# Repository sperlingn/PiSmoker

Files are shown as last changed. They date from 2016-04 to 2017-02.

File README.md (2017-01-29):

# PiSmoker

##Dependencies
* RPI.GPIO
* spidev
* [Adafruit_Python_CharLCD](https://github.com/adafruit/Adafruit_Python_CharLCD)
* [Python-firebase](https://github.com/ozgur/python-firebase) Use github version instead of pip

## Schematics and Boards
* PiSmoker_pwr_triac_isol -- AC handling board, includes SW PS for backpowering Raspi.
* PiSmoker_sig_v1.1 -- Signal boards, conforms to Pi HAT specifications, including EEPROM.

Signal board and power board for traic based control.  Includes board power with isolation and 4 triacs.  Signaling board has space for 1 RTD via MAX31865, 2 thermocouples (and internal temperature sensor) via ADS1118, and 2 thermocouples and 4 thermistor probes via MCP3208.  Using MAX31865 temperature for CJC for all thermocouples should be possible due to placement underneath connector.

## Work to be done

* TODO: Add support for firebox burnout sensor (purpose of TC1, hotbox TC to see if temp is >setpoint, will require testing temps).  Should be able to run igniter if it is sensed early enough without having to clear out the firebox of pellets or blow the temperature range.
* TODO: Add parsing of EEPROM settings.

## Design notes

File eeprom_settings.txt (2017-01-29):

########################################################################
# EEPROM settings text file
#
# Edit this file for your particular board and run through eepmake tool,
# then use eepflash tool to write to attached HAT ID EEPROM
#
# Tools available:
#  eepmake   Parses EEPROM text file and creates binary .eep file
#  eepdump   Dumps a binary .eep file as human readable text (for debug)
#  eepflash  Write or read .eep binary image to/from HAT EEPROM
#
########################################################################

########################################################################
# Vendor info

# 128 bit UUID. If left at zero eepmake tool will auto-generate
# RFC 4122 compliant UUID
product_uuid 00000000-0000-0000-0000-000000000000

# 16 bit product id
product_id 0x0001

# 16 bit product version
product_ver 0x0001

# ASCII vendor string  (max 255 characters)
vendor "PiSmoker"

# ASCII product string (max 255 characters)
product "PiSmoker interface board v1.1"

########################################################################
# GPIO bank settings, set to nonzero to change from the default.
# NOTE these setting can only be set per BANK, uncommenting any of
# these will force the bank to use the custom setting.

# drive strength, 0=default, 1-8=2,4,6,8,10,12,14,16mA, 9-15=reserved
gpio_drive 4

# 0=default, 1=slew rate limiting, 2=no slew limiting, 3=reserved
gpio_slew 0

# 0=default, 1=hysteresis disabled, 2=hysteresis enabled, 3=reserved
gpio_hysteresis 0

# If board back-powers Pi via 5V GPIO header pins:
# 0 = board does not back-power
# 1 = board back-powers and can supply the Pi with a minimum of 1.3A
# 2 = board back-powers and can supply the Pi with a minimum of 2A
# 3 = reserved
# If back_power=2 then USB high current mode will be automatically
# enabled on the Pi
back_power 2

########################################################################
# GPIO pins, uncomment for GPIOs used on board
# Options for FUNCTION: INPUT, OUTPUT, ALT0-ALT5
# Options for PULL: DEFAULT, UP, DOWN, NONE
# NB GPIO0 and GPIO1 are reserved for ID EEPROM so cannot be set

#         GPIO  FUNCTION  PULL
#         ----  --------  ----
setgpio  2     OUTPUT     NONE
setgpio  3     OUTPUT     NONE
setgpio  4     OUTPUT     NONE
setgpio  5     OUTPUT     NONE
#setgpio  6     INPUT     DEFAULT
#setgpio  7     INPUT     DEFAULT
#setgpio  8     INPUT     DEFAULT
#setgpio  9     INPUT     DEFAULT
#setgpio  10    INPUT     DEFAULT
#setgpio  11    INPUT     DEFAULT
#setgpio  12    INPUT     DEFAULT
#setgpio  13    INPUT     DEFAULT
#setgpio  14    INPUT     DEFAULT
#setgpio  15    INPUT     DEFAULT
setgpio  16    ALT4     DEFAULT
setgpio  17    ALT4     DEFAULT
setgpio  18    ALT4     DEFAULT
setgpio  19    ALT4     DEFAULT
setgpio  20    ALT4     DEFAULT
setgpio  21    ALT4     DEFAULT
#setgpio  22    INPUT     DEFAULT
#setgpio  23    INPUT     DEFAULT
#setgpio  24    INPUT     DEFAULT
#setgpio  25    INPUT     DEFAULT
#setgpio  26    INPUT     DEFAULT
#setgpio  27    INPUT     DEFAULT

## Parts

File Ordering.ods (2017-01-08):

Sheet: MOUSER
 |  |  | PISMOKER
Order Qty. | P# | Qty | Mouser # | Mfr. # | Manufacturer | Customer # | Description | RoHS | Lifecycle | Order Qty. | Price (USD) | Ext.: (USD)
1 | 21 | 1 | 579-MCP3208CISL | MCP3208-CI/SL | Microchip |  | Analog to Digital Converters - ADC 12-bit SPI 8 Chl | RoHS Compliant |  | 1 | $3.66 | $3.66
1 | 18 | 1 | 595-ADS1118IDGSR | ADS1118IDGSR | Texas Instruments |  | Analog to Digital Converters - ADC 16B ADC w/Integrated MUX | RoHS Compliant |  | 1 | $5.48 | $5.48
1 | 20 | 1 | 700-MAX31865AAP+ | MAX31865AAP+ | Maxim Integrated |  | Data Acquisition ADCs/DACs - Specialized | RoHS Compliant | New At Mouser | 1 | $3.47 | $3.47
2 | 20 | 1 | 660-RN732BTTD4001B25 | RN732BTTD4001B25 | KOA Speer |  | Thin Film Resistors - SMD 4kOhm,1206,0.1%,25pp m,125mW,150V | RoHS Compliant By Exemption |  | 2 | $0.49 | $0.98
4 | 20 | 1 | 588-AS08J1001ET | AS08J1001ET | Ohmite |  | Thick Film Resistors - SMD 330 mW 1000 OHM 5% ANTI SURGE | RoHS Compliant | New At Mouser | 4 | $0.06 | $0.24
8 | 20 | #N/A | 538-03-06-2023 | 03-06-2023 | Molex |  | Pin & Socket Connectors 2 CKT PLUG NATURAL | RoHS Compliant |  | 8 | $0.18 | $1.44
16 | 20 | #N/A | 538-02-06-2103 | 02-06-2103 | Molex |  | Pin & Socket Connectors CRIMP PIN BULK 18-24 | RoHS Compliant |  | 16 | $0.117 | $1.87
3 | 20 | 1 | 698-CAT24C256WI-GT3 | CAT24C256WI-GT3 | ON Semiconductor |  | EEPROM 256kb I2C Serial CMOS EEPROM | RoHS Compliant |  | 3 | $0.65 | $1.95
1 | 20 | 1 | 709-IRM20-5 | IRM-20-5 | Mean Well |  | AC/DC Power Modules 5V 4A 20W 85-264Vin Encap PS | RoHS Compliant |  | 1 | $11.07 | $11.07
1 | 20 | #N/A | 611-DA102J3RS215QF8 | DA102J3RS215QF8 | C&K Components |  | Illuminated Rocker Switches SPST 16A ON-OFF RED | RoHS Compliant |  | 1 | $1.16 | $1.16
10 | 20 | 13 | 710-885012207072 | 885012207072 | Wurth Electronics |  | Multilayer Ceramic Capacitors MLCC - SMD/SMT WCAP-CSGP 100000pF 0805 10% 25V MLCC | RoHS Compliant | New Product | 10 | $0.05 | $0.50
10 | 20 | 1 | 710-885012207011 | 885012207011 | Wurth Electronics |  | Multilayer Ceramic Capacitors MLCC - SMD/SMT WCAP-CSGP 10000pF 0805 10% 10V MLCC | RoHS Compliant | New Product | 10 | $0.07 | $0.70
5 | 20 | 2 | 755-ESR10EZPJ392 | ESR10EZPJ392 | ROHM Semiconductor |  | Thick Film Resistors - SMD 0805 3K9ohm 5% Anti Surge AEC-Q200 | RoHS Compliant | New Product | 5 | $0.10 | $0.50
3 | 20 | 1 | 621-DMG2305UX-7 | DMG2305UX-7 | Diodes Incorporated |  | MOSFET P-Ch ENH FET -20V 52mOhm -5.0V | RoHS Compliant |  | 3 | $0.37 | $1.11
3 | 20 | 1 | 621-DMMT5401-7-F | DMMT5401-7-F | Diodes Incorporated |  | Bipolar Transistors - BJT MATCHED PNP SM SIGNAL TRANS | RoHS Compliant |  | 3 | $0.42 | $1.26
3 | 20 | 1 | 71-CRCW0805-47K-E3 | CRCW080547K0FKEA | Vishay |  | Thick Film Resistors - SMD 1/8watt 47Kohms 1% 100ppm | RoHS Compliant By Exemption |  | 3 | $0.10 | $0.30
14 | 20 | 8 | 588-AS08J1004ET | AS08J1004ET | Ohmite |  | Thick Film Resistors - SMD 330 mW 1mOhm 5% ANTI SURGE | RoHS Compliant | New At Mouser | 14 | $0.048 | $0.67
14 | 20 | 8 | 652-CR0805FX-4990ELF | CR0805-FX-4990ELF | Bourns |  | Thick Film Resistors - SMD 499ohm 1% | RoHS Compliant By Exemption |  | 14 | $0.038 | $0.53
10 | 20 | 4 | 77-VJ0805Y105KXQTBC | VJ0805Y105KXQTW1BC | Vishay |  | Multilayer Ceramic Capacitors MLCC - SMD/SMT 0805 1uF 10volts X7R 10% | RoHS Compliant |  | 10 | $0.05 | $0.50
8 | 20 | #N/A | 855-R25-1001302 | R25-1001302 | Harwin |  | Standoffs & Spacers M2.5 x 13mm HEX BRASS 5mm A/F | RoHS Compliant By Exemption |  | 8 | $0.44 | $3.52
10 | 20 | 4 | 279-CPF0805B22KE1 | CPF0805B22KE | TE Connectivity |  | Thin Film Resistors - SMD CPF0805 22K 0.1% 25PPM | RoHS Compliant |  | 10 | $0.15 | $1.50
10 | 20 | 1 | 284-APC0805B10K0N | APC0805B10K0N | Ohmite |  | Thin Film Resistors - SMD 10KOhm 0.1% 0805 25 PPM | RoHS Compliant | New Product | 10 | $0.097 | $0.97
2 | 20 | 2 | 855-M20-7812045 | M20-7812045 | Harwin |  | Headers & Wire Housings 20+20 DIL 2.54MM L/P SMT SKT | RoHS Compliant | New Product | 2 | $3.96 | $7.92
2 | 20 | 2 | 855-M20-8762042 | M20-8762042 | Harwin |  | Headers & Wire Housings 20+20 DIL VERTICAL SMT HEADER GOLD+TIN | RoHS Compliant |  | 2 | $2.05 | $4.10
2 | 20 | 2 | 855-M20-7872042 | M20-7872042 | Harwin |  | Headers & Wire Housings 20+20 DIL SMT SKT BTM ENT SEL GLD+TIN | RoHS Compliant |  | 2 | $4.97 | $9.94
25 | 20 | 16 | 667-ERJ-P06J301V | ERJ-P06J301V | Panasonic |  | Thick Film Resistors - SMD 0805 300ohms 5% Thick Film Resistor | RoHS Compliant By Exemption |  | 25 | $0.058 | $1.45
5 | 20 | 4 | 771-BTA312B-800E,118 | BTA312B-800E,118 | NXP |  | Triacs Thyristor TRIAC 800V 105A 3-Pin (2+Tab) | RoHS Compliant |  | 5 | $1.07 | $5.35
5 | 20 | 4 | 638-EL3063S1TAV | EL3063S1(TA)-V | Everlight |  | Triac & SCR Output Optocouplers 600PBV 5000Vrms -55 to +100 Op Temp | RoHS Compliant |  | 5 | $0.97 | $4.85
6 | 20 | 4 | 810-CGA5L4C0G2J103J | CGA5L4C0G2J103J160AA | TDK |  | Multilayer Ceramic Capacitors MLCC - SMD/SMT 1206 0.01uF 630volts C0G +/-5% Auto | RoHS Compliant |  | 6 | $0.49 | $2.94
1 | 20 | 1 | 693-0031.8263 | 0031.8263 | Schurter |  | Fuse Holder OGN-SMD FUSEHOLDER 5X20 | RoHS Compliant |  | 1 | $1.39 | $1.39
1 | 20 | 1 | 651-1771088 | 1771088 | Phoenix Contact |  | Fixed Terminal Blocks PTSM 0,5/ 8-2,5-H SMD R44 | RoHS Compliant |  | 1 | $1.40 | $1.40
1 | 20 | 1 | 651-1771062 | 1771062 | Phoenix Contact |  | Fixed Terminal Blocks PTSM 0,5/ 6-2,5-H SMD R44 | RoHS Compliant |  | 1 | $1.22 | $1.22

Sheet: QTY
Qty | Value | Device | Package | Mouser | Parts | Description | TOLERANCE
1 |  | PHOENIX_PTS1,5-6PTSM0,5 | PHOENIX_PTSM0,5/6-2,5-H_SMD_R44 | 651-1771062 | X2 | PHOENIX
1 |  | TERMINAL_BLOCK-8PTSM0,5 | PHOENIX_PTSM0,5/8-2,5-H_SMD_R44 | 651-1771088 | X1 | PHOENIX
13 | 100nF | C-EUC0805K | C0805K | 710-885012207072 | C1, C3, C4, C5, C6, C7, C9, C10, C12, C13, C15, C16, C17 | CAPACITOR, European symbol
1 | 10nF | C-EUC0805 | C0805 | 710-885012207011 | C2 | CAPACITOR, European symbol
4 | 10nF | C-EUC1206 | C1206 | 810-CGA5L4C0G2J103J | C1, C2, C3, C4 | CAPACITOR, European symbol
4 | 1uF | C-EUC0805K | C0805K | 77-VJ0805Y105KXQTBC | C8, C11, C14, C18 | CAPACITOR, European symbol
8 | 1M | R-EU_M0805 | M0805 | 588-AS08J1004ET | R8, R9, R12, R13, R16, R17, R20, R21 | RESISTOR, European symbol | 5%
1 | 47k | R-EU_M0805 | M0805 | 71-CRCW0805-47K-E3 | R2 | RESISTOR, European symbol | 1%
4 | 22k | R-EU_R0805 | R0805 | 279-CPF0805B22KE1 | R6, R24, R26, R28 | RESISTOR, European symbol | 0.10%
1 | 10K | R-EU_M0805 | M0805 | 284-APC0805B10K0N | R1 | RESISTOR, European symbol | 1%
4 | 10k | R-EU_R0805 | R0805 | 284-APC0805B10K0N | R5, R23, R25, R27 | RESISTOR, European symbol | 0.10%
1 | 4k | R-EU_R1206 | R1206 | 660-RN732BTTD4001B25 | R4 | RESISTOR, European symbol | 0.10%
2 | 3k9 | R-EU_M0805 | M0805 | 755-ESR10EZPJ392 | R1, R2 | RESISTOR, European symbol | 5%
1 | 1k | R-EU_M0805 | M0805 | 588-AS08J1001ET | R3 | RESISTOR, European symbol | 5%
8 | 499 | R-EU_M0805 | M0805 | 652-CR0805FX-4990ELF | R7, R10, R11, R14, R15, R18, R19, R22 | RESISTOR, European symbol | 5%
16 | 300 | R-EU_M0805 | M0805 | 667-ERJ-P06J301V | R3, R4, R5, R6, R7, R8, R9, R10, R11, R12, R13, R14, R15, R16, R17, R18 | RESISTOR, European symbol | 5%
1 | ADS1118 | ADS1118 | DGS10 | 595-ADS1118IDGSR | U$1 | ADS1118
1 | EEPROM24 | CAT24C256WI-GT3 | SOIC8 | 698-CAT24C256WI-GT3 | U1
1 | MAX31865 | MAX31865 | SSOP20_A20-1 | 700-MAX31865AAP+ | U$2 | RTD to Digital Converter
1 | MCP3208 | MCP3208 | SOIC16-N_MC | 579-MCP3208CISL | U$3
1 | 5AL250V | OGN_FUSE | OGN_SMD | 693-0031.8263 | F1 | FUSE HOLDER grid 22,5 mm, OGN0031 8201, Schurter (Buerklin)
1 | 5V | IRM_15/20 | IRM_15/20 | 709-IRM20-5 | IRM-20-5 | 15 or 20 watt
1 | BSS84 | BSS84 | SOT23 | 621-DMG2305UX-7 | Q1 | P-CHANNEL MOS FET
4 | BTA312B | BTA312B | D2PAK-3 | 771-BTA312B-800E,118 | U1, U2, U3, U4
4 | EL3063S1 | EL3063S1 | SMD6 | 638-EL3063S1TAV | OK1, OK2, OK3, OK4 | 6-Pin DIP Zero-Cross Optoisolators Triac Driver Output (250/400 Volt Peak)
1 | PNP2 | PNP2 | SOT26 | 621-DMMT5401-7-F | T1 | Dual PNP TRANSISTOR
2 |  | M20-781_SMD | M20-781_SMD_LOWER_NOHOLES | 855-M20-7812045 | X1 | 2x20 header connector, all pins connected
2 |  | M20-876_SMD | M20-781_SMD_LOWER_876_UPPER | 855-M20-8762042 | X3 | 2x20 header connector, all pins connected
2 |  |  |  | 855-M20-7872042

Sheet: Signal_Board_Placement
Part | Value | Device | Package | Description | COPYRIGHT | DATASHEETURL | DIELECTRIC | FAMILY_NAME | GENERIC_PART_NUMBER | INDUSTRY_STD_PKG_TYPE | MANUFACTURER | MANUFACTURER_PART_NUMBER | P1 | P2 | P3 | P4 | P5 | P6 | P7 | P8 | PACKAGE_DESIGNATOR | PIN_COUNT | TOLERANCE | VENDOR
C1 | 100nF | C-EUC0805K | C0805K | CAPACITOR, European symbol |  |  | X7R
C2 | 10nF | C-EUC0805 | C0805 | CAPACITOR, European symbol
C3 | 100nF | C-EUC0805K | C0805K | CAPACITOR, European symbol |  |  | X7R
C4 | 100nF | C-EUC0805K | C0805K | CAPACITOR, European symbol |  |  | X7R
C5 | 100nF | C-EUC0805K | C0805K | CAPACITOR, European symbol |  |  | X7R
C6 | 100nF | C-EUC0805K | C0805K | CAPACITOR, European symbol |  |  | X7R
C7 | 100nF | C-EUC0805K | C0805K | CAPACITOR, European symbol |  |  | X7R
C8 | 1uF | C-EUC0805K | C0805K | CAPACITOR, European symbol |  |  | X7R
C9 | 100nF | C-EUC0805K | C0805K | CAPACITOR, European symbol |  |  | X7R
C10 | 100nF | C-EUC0805K | C0805K | CAPACITOR, European symbol |  |  | X7R
C11 | 1uF | C-EUC0805K | C0805K | CAPACITOR, European symbol |  |  | X7R
C12 | 100nF | C-EUC0805K | C0805K | CAPACITOR, European symbol |  |  | X7R
C13 | 100nF | C-EUC0805K | C0805K | CAPACITOR, European symbol |  |  | X7R
C14 | 1uF | C-EUC0805K | C0805K | CAPACITOR, European symbol |  |  | X7R
C15 | 100nF | C-EUC0805K | C0805K | CAPACITOR, European symbol |  |  | X7R
C16 | 100nF | C-EUC0805K | C0805K | CAPACITOR, European symbol |  |  | X7R
C17 | 100nF | C-EUC0805K | C0805K | CAPACITOR, European symbol |  |  | X7R
C18 | 1uF | C-EUC0805K | C0805K | CAPACITOR, European symbol |  |  | X7R
CFG |  | SOLDERJUMPERCLOSED | SOLDERJUMPER_CLOSEDWIRE | SMD Solder JUMPER
R1 | 3k9 | R-EU_M0805 | M0805 | RESISTOR, European symbol |  |  |  |  |  |  |  |  |  |  |  |  |  |  |  |  |  |  | 5%
R2 | 3k9 | R-EU_M0805 | M0805 | RESISTOR, European symbol |  |  |  |  |  |  |  |  |  |  |  |  |  |  |  |  |  |  | 5%
R3 | 1k | R-EU_M0805 | M0805 | RESISTOR, European symbol |  |  |  |  |  |  |  |  |  |  |  |  |  |  |  |  |  |  | 5%
R4 | 4k | R-EU_R1206 | R1206 | RESISTOR, European symbol |  |  |  |  |  |  |  |  |  |  |  |  |  |  |  |  |  |  | 0.10%
R5 | 10k | R-EU_R0805 | R0805 | RESISTOR, European symbol |  |  |  |  |  |  |  |  |  |  |  |  |  |  |  |  |  |  | 0.10%
R6 | 22k | R-EU_R0805 | R0805 | RESISTOR, European symbol |  |  |  |  |  |  |  |  |  |  |  |  |  |  |  |  |  |  | 0.10%
R7 | 499 | R-EU_M0805 | M0805 | RESISTOR, European symbol |  |  |  |  |  |  |  |  |  |  |  |  |  |  |  |  |  |  | 5%
R8 | 1M | R-EU_M0805 | M0805 | RESISTOR, European symbol |  |  |  |  |  |  |  |  |  |  |  |  |  |  |  |  |  |  | 5%
R9 | 1M | R-EU_M0805 | M0805 | RESISTOR, European symbol |  |  |  |  |  |  |  |  |  |  |  |  |  |  |  |  |  |  | 5%
R10 | 499 | R-EU_M0805 | M0805 | RESISTOR, European symbol |  |  |  |  |  |  |  |  |  |  |  |  |  |  |  |  |  |  | 5%
R11 | 499 | R-EU_M0805 | M0805 | RESISTOR, European symbol |  |  |  |  |  |  |  |  |  |  |  |  |  |  |  |  |  |  | 5%
R12 | 1M | R-EU_M0805 | M0805 | RESISTOR, European symbol |  |  |  |  |  |  |  |  |  |  |  |  |  |  |  |  |  |  | 5%
R13 | 1M | R-EU_M0805 | M0805 | RESISTOR, European symbol |  |  |  |  |  |  |  |  |  |  |  |  |  |  |  |  |  |  | 5%
R14 | 499 | R-EU_M0805 | M0805 | RESISTOR, European symbol |  |  |  |  |  |  |  |  |  |  |  |  |  |  |  |  |  |  | 5%
R15 | 499 | R-EU_M0805 | M0805 | RESISTOR, European symbol |  |  |  |  |  |  |  |  |  |  |  |  |  |  |  |  |  |  | 5%
R16 | 1M | R-EU_M0805 | M0805 | RESISTOR, European symbol |  |  |  |  |  |  |  |  |  |  |  |  |  |  |  |  |  |  | 5%
R17 | 1M | R-EU_M0805 | M0805 | RESISTOR, European symbol |  |  |  |  |  |  |  |  |  |  |  |  |  |  |  |  |  |  | 5%
R18 | 499 | R-EU_M0805 | M0805 | RESISTOR, European symbol |  |  |  |  |  |  |  |  |  |  |  |  |  |  |  |  |  |  | 5%
R19 | 499 | R-EU_M0805 | M0805 | RESISTOR, European symbol |  |  |  |  |  |  |  |  |  |  |  |  |  |  |  |  |  |  | 5%
R20 | 1M | R-EU_M0805 | M0805 | RESISTOR, European symbol |  |  |  |  |  |  |  |  |  |  |  |  |  |  |  |  |  |  | 5%
R21 | 1M | R-EU_M0805 | M0805 | RESISTOR, European symbol |  |  |  |  |  |  |  |  |  |  |  |  |  |  |  |  |  |  | 5%
R22 | 499 | R-EU_M0805 | M0805 | RESISTOR, European symbol |  |  |  |  |  |  |  |  |  |  |  |  |  |  |  |  |  |  | 5%
R23 | 10k | R-EU_R0805 | R0805 | RESISTOR, European symbol |  |  |  |  |  |  |  |  |  |  |  |  |  |  |  |  |  |  | 0.10%
R24 | 22k | R-EU_R0805 | R0805 | RESISTOR, European symbol |  |  |  |  |  |  |  |  |  |  |  |  |  |  |  |  |  |  | 0.10%
R25 | 10k | R-EU_R0805 | R0805 | RESISTOR, European symbol |  |  |  |  |  |  |  |  |  |  |  |  |  |  |  |  |  |  | 0.10%
R26 | 22k | R-EU_R0805 | R0805 | RESISTOR, European symbol |  |  |  |  |  |  |  |  |  |  |  |  |  |  |  |  |  |  | 0.10%
R27 | 10k | R-EU_R0805 | R0805 | RESISTOR, European symbol |  |  |  |  |  |  |  |  |  |  |  |  |  |  |  |  |  |  | 0.10%
R28 | 22k | R-EU_R0805 | R0805 | RESISTOR, European symbol |  |  |  |  |  |  |  |  |  |  |  |  |  |  |  |  |  |  | 0.10%
SJ1 |  | SOLDERJUMPER_2WAY | SOLDERJUMPER_2WAY_ARROW_NOPASTE | 2-Way Solder Jumper
SJ2 |  | SOLDERJUMPER_2WAY | SOLDERJUMPER_2WAY_ARROW_NOPASTE | 2-Way Solder Jumper
SJ3 |  | SOLDERJUMPER_2WAY | SOLDERJUMPER_2WAY_ARROW_NOPASTE | 2-Way Solder Jumper
SJ4 |  | SOLDERJUMPER_2WAY | SOLDERJUMPER_2WAY_ARROW_NOPASTE | 2-Way Solder Jumper
U$1 | ADS1118 | ADS1118 | DGS10 | ADS1118 | Copyright C 2015 Accelerated Designs. All rights reserved | httpwww.ti.comlitgpnADS1118 |  | PRECISION ADC <=10MSPS | ADS1118 | MSOP | Texas Instruments | ADS1118_DGS_10 |  |  |  |  |  |  |  |  | DGS | 10 |  | Texas Instruments
U$2 | MAX31865 | MAX31865 | SSOP20_A20-1 | RTD to Digital Converter
U$3 | MCP3208 | MCP3208 | SOIC16-N_MC
U1 | EEPROM24 | EEPROM24 | SOIC8
X1 |  | TERMINAL_BLOCK-8PTSM0,5 | PHOENIX_PTSM0,5/8-2,5-H_SMD_R44 | PHOENIX |  |  |  |  |  |  |  |  | RTD1+ | RTD1- | TC1+ | TC1- | TC2- | TC2+ | TC3+ | TC3-
X2 |  | PHOENIX_PTS1,5-6PTSM0,5 | PHOENIX_PTSM0,5/6-2,5-H_SMD_R44 | PHOENIX |  |  |  |  |  |  |  |  | TC4+ | TC4- | RT1+ | RT2+ | RT3+ | RT4+
X3 | RASPI_GPIO_3B_SPI1_M20-781LOWER-876_UPPER | RASPI_GPIO_3B_SPI1_M20-781LOWER-876_UPPER | M20-781_SMD_LOWER_876_UPPER | 2x20 header connector, all pins connected

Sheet: Power_Board_Placement
Part | Value | Device | Package | Description | MF | MPN | OC_FARNELL | OC_NEWARK | TOLERANCE
AC/LINE | SOLDER_PAD | SOLDER_PAD | SOLDER_PAD_18AWG
AC/N1 | SOLDER_PAD | SOLDER_PAD | SOLDER_PAD_18AWG
AUGER | SOLDER_PAD | SOLDER_PAD | SOLDER_PAD_18AWG
BLOWER | SOLDER_PAD | SOLDER_PAD | SOLDER_PAD_18AWG
C1 | 10nF | C-EUC1206 | C1206 | CAPACITOR, European symbol
C2 | 10nF | C-EUC1206 | C1206 | CAPACITOR, European symbol
C3 | 10nF | C-EUC1206 | C1206 | CAPACITOR, European symbol
C4 | 10nF | C-EUC1206 | C1206 | CAPACITOR, European symbol
F1 | 5AL250V | OGN_FUSE | OGN_SMD | FUSE HOLDER grid 22,5 mm, OGN0031 8201, Schurter (Buerklin) | SCHURTER | 31.8201 | 1162740 | 96F8317
IGNITER | SOLDER_PAD | SOLDER_PAD | SOLDER_PAD_18AWG
IRM-20-5 | 5V | IRM_15/20 | IRM_15/20 | 15 or 20 watt
OK1 | EL3063S1 | EL3063S1 | SMD6 | 6-Pin DIP Zero-Cross Optoisolators Triac Driver Output (250/400 Volt Peak)
OK2 | EL3063S1 | EL3063S1 | SMD6 | 6-Pin DIP Zero-Cross Optoisolators Triac Driver Output (250/400 Volt Peak)
OK3 | EL3063S1 | EL3063S1 | SMD6 | 6-Pin DIP Zero-Cross Optoisolators Triac Driver Output (250/400 Volt Peak)
OK4 | EL3063S1 | EL3063S1 | SMD6 | 6-Pin DIP Zero-Cross Optoisolators Triac Driver Output (250/400 Volt Peak)
Q1 | BSS84 | BSS84 | SOT23 | P-CHANNEL MOS FET
R1 | 10K | R-EU_M0805 | M0805 | RESISTOR, European symbol |  |  |  |  | 1%
R2 | 47k | R-EU_M0805 | M0805 | RESISTOR, European symbol |  |  |  |  | 1%
R3 | 300 | R-EU_M0805 | M0805 | RESISTOR, European symbol |  |  |  |  | 5%
R4 | 300 | R-EU_M0805 | M0805 | RESISTOR, European symbol |  |  |  |  | 5%
R5 | 300 | R-EU_M0805 | M0805 | RESISTOR, European symbol |  |  |  |  | 5%
R6 | 300 | R-EU_M0805 | M0805 | RESISTOR, European symbol |  |  |  |  | 5%
R7 | 300 | R-EU_M0805 | M0805 | RESISTOR, European symbol |  |  |  |  | 5%
R8 | 300 | R-EU_M0805 | M0805 | RESISTOR, European symbol |  |  |  |  | 5%
R9 | 300 | R-EU_M0805 | M0805 | RESISTOR, European symbol |  |  |  |  | 5%
R10 | 300 | R-EU_M0805 | M0805 | RESISTOR, European symbol |  |  |  |  | 5%
R11 | 300 | R-EU_M0805 | M0805 | RESISTOR, European symbol |  |  |  |  | 5%
R12 | 300 | R-EU_M0805 | M0805 | RESISTOR, European symbol |  |  |  |  | 5%
R13 | 300 | R-EU_M0805 | M0805 | RESISTOR, European symbol |  |  |  |  | 5%
R14 | 300 | R-EU_M0805 | M0805 | RESISTOR, European symbol |  |  |  |  | 5%
R15 | 300 | R-EU_M0805 | M0805 | RESISTOR, European symbol |  |  |  |  | 5%
R16 | 300 | R-EU_M0805 | M0805 | RESISTOR, European symbol |  |  |  |  | 5%
R17 | 300 | R-EU_M0805 | M0805 | RESISTOR, European symbol |  |  |  |  | 5%
R18 | 300 | R-EU_M0805 | M0805 | RESISTOR, European symbol |  |  |  |  | 5%
SPARE | SOLDER_PAD | SOLDER_PAD | SOLDER_PAD_18AWG
T1 | PNP2 | PNP2 | SOT26 | Dual PNP TRANSISTOR
U1 | BTA312B | BTA312B | D2PAK-3
U2 | BTA312B | BTA312B | D2PAK-3
U3 | BTA312B | BTA312B | D2PAK-3
U4 | BTA312B | BTA312B | D2PAK-3
X1 | RASPI_GPIO_3B_SPI1_M20-781_SMD_LOWER_NOHOLES | RASPI_GPIO_3B_SPI1_M20-781_SMD_LOWER_NOHOLES | M20-781_SMD_LOWER_NOHOLES | 2x20 header connector, all pins connected

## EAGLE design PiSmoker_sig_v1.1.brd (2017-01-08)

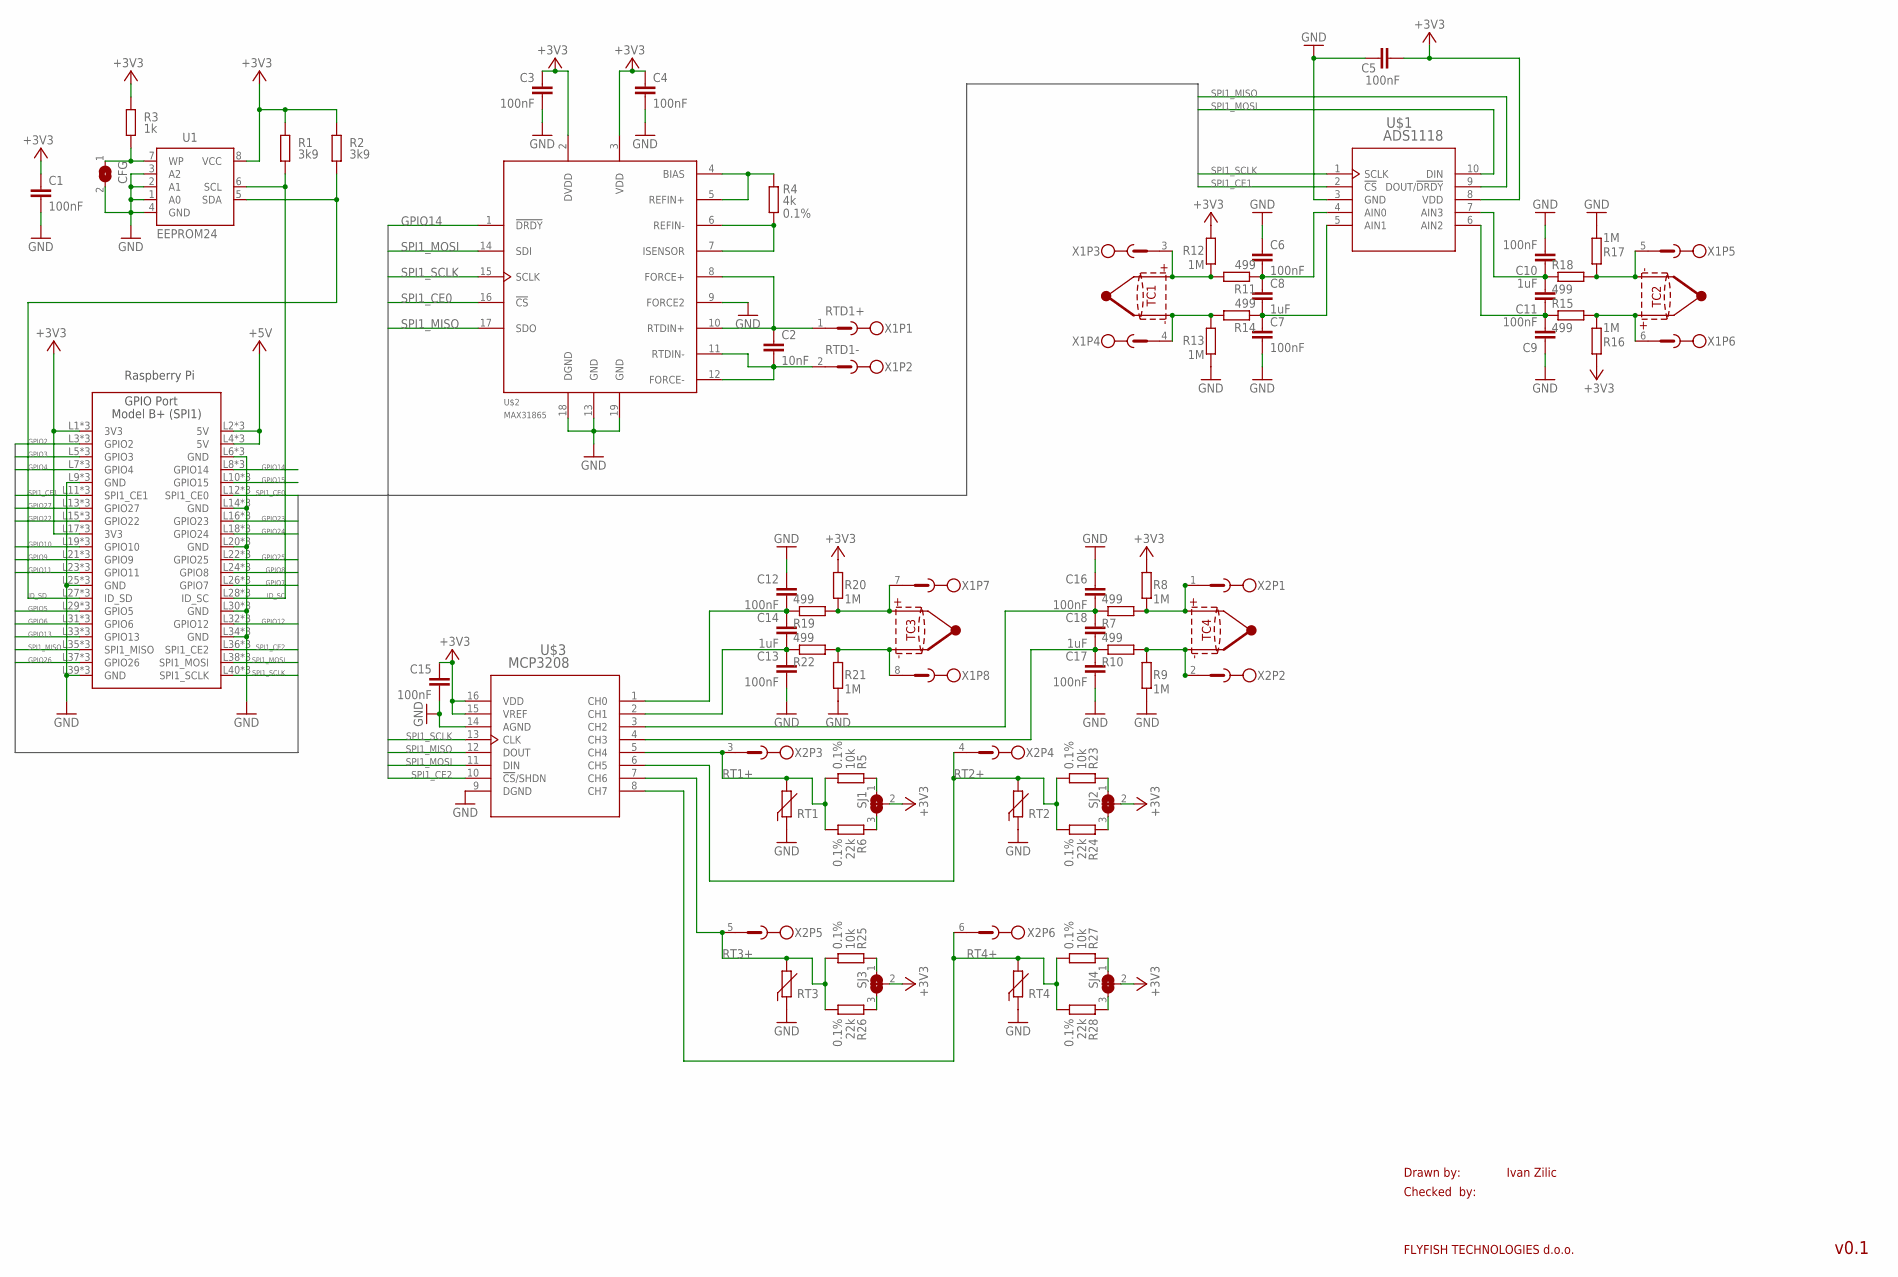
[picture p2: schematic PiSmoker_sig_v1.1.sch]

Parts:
C1, C3, C4, C5, C6, C7, C9, C10, C12, C13, C15, C16, C17: 100nF; C0805K
C2: 10nF; C0805
C8, C11, C14, C18: 1uF; C0805K
CFG: SOLDERJUMPERCLOSED; SOLDERJUMPER_CLOSEDWIRE
R1, R2: 3k9; M0805; TOLERANCE 5%
R3: 1k; M0805; TOLERANCE 5%
R4: 4k; R1206; TOLERANCE 0.1%
R5, R23, R25, R27: 10k; R0805; TOLERANCE 0.1%
R6, R24, R26, R28: 22k; R0805; TOLERANCE 0.1%
R7, R10, R11, R14, R15, R18, R19, R22: 499; M0805; TOLERANCE 5%
R8, R9, R12, R13, R16, R17, R20, R21: 1M; M0805; TOLERANCE 5%
SJ1, SJ2, SJ3, SJ4: SOLDERJUMPER_2WAY; SOLDERJUMPER_2WAY_ARROW_NOPASTE
U1: EEPROM24; SOIC8
U$1: ADS1118; DGS10
U$2: MAX31865; SSOP20_A20-1
U$3: MCP3208; SOIC16-N_MC
X1: TERMINAL_BLOCK-8PTSM0,5; PHOENIX_PTSM0,5/8-2,5-H_SMD_R44
X2: PHOENIX_PTS1,5-6PTSM0,5; PHOENIX_PTSM0,5/6-2,5-H_SMD_R44
X3: RASPI_GPIO_3B_SPI1_M20-781LOWER-876_UPPER; M20-781_SMD_LOWER_876_UPPER

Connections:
+3V3: C1.1, C3.1, C4.1, C5.2, C15.1, R1.2, R2.2, R3.2, R8.1, R12.1, R16.1, R20.1, SJ1.2, SJ2.2, SJ3.2, SJ4.2, U1.8 (VCC), U$1.8 (VDD), U$2.2 (DVDD), U$2.3 (VDD), U$3.15 (VREF), U$3.16 (VDD), X3.L1 (3V3), X3.L17 (3V3), X3.P1 (3V3), X3.P17 (3V3), X3.U1 (3V3), X3.U17 (3V3)
+5V: X3.L2 (5V), X3.L4 (5V), X3.P2 (5V), X3.P4 (5V), X3.U2 (5V), X3.U4 (5V)
GND: C1.2, C3.2, C4.2, C5.1, C6.1, C7.2, C9.1, C10.2, C12.1, C13.2, C15.2, C16.1, C17.2, CFG.2, R9.2, R13.2, R17.2, R21.2, U1.1 (A0), U1.2 (A1), U1.3 (A2), U1.4 (GND), U$1.3 (GND), U$2.9 (FORCE2), U$2.13 (GND), U$2.18 (DGND), U$2.19 (GND), U$3.9 (DGND), U$3.14 (AGND), X3.L6 (GND), X3.L9 (GND), X3.L14 (GND), X3.L20 (GND), X3.L25 (GND), X3.L30 (GND), X3.L34 (GND), X3.L39 (GND), X3.P6 (GND), X3.P9 (GND), X3.P14 (GND), X3.P20 (GND), X3.P25 (GND), X3.P30 (GND), X3.P34 (GND), X3.P39 (GND), X3.U6 (GND), X3.U9 (GND), X3.U14 (GND), X3.U20 (GND), X3.U25 (GND), X3.U30 (GND), X3.U34 (GND), X3.U39 (GND)
GPIO2: X3.L3 (GPIO2), X3.P3 (GPIO2), X3.U3 (GPIO2)
GPIO3: X3.L5 (GPIO3), X3.P5 (GPIO3), X3.U5 (GPIO3)
GPIO4: X3.L7 (GPIO4), X3.P7 (GPIO4), X3.U7 (GPIO4)
GPIO5: X3.L29 (GPIO5), X3.P29 (GPIO5), X3.U29 (GPIO5)
GPIO6: X3.L31 (GPIO6), X3.P31 (GPIO6), X3.U31 (GPIO6)
GPIO7: X3.L26 (GPIO7), X3.P26 (GPIO7), X3.U26 (GPIO7)
GPIO8: X3.L24 (GPIO8), X3.P24 (GPIO8), X3.U24 (GPIO8)
GPIO9: X3.L21 (GPIO9), X3.P21 (GPIO9), X3.U21 (GPIO9)
GPIO10: X3.L19 (GPIO10), X3.P19 (GPIO10), X3.U19 (GPIO10)
GPIO11: X3.L23 (GPIO11), X3.P23 (GPIO11), X3.U23 (GPIO11)
GPIO12: X3.L32 (GPIO12), X3.P32 (GPIO12), X3.U32 (GPIO12)
GPIO13: X3.L33 (GPIO13), X3.P33 (GPIO13), X3.U33 (GPIO13)
GPIO14: U$2.1 (!DRDY), X3.L8 (GPIO14), X3.P8 (GPIO14), X3.U8 (GPIO14)
GPIO15: X3.L10 (GPIO15), X3.P10 (GPIO15), X3.U10 (GPIO15)
GPIO22: X3.L15 (GPIO22), X3.P15 (GPIO22), X3.U15 (GPIO22)
GPIO23: X3.L16 (GPIO23), X3.P16 (GPIO23), X3.U16 (GPIO23)
GPIO24: X3.L18 (GPIO24), X3.P18 (GPIO24), X3.U18 (GPIO24)
GPIO25: X3.L22 (GPIO25), X3.P22 (GPIO25), X3.U22 (GPIO25)
GPIO26: X3.L37 (GPIO26), X3.P37 (GPIO26), X3.U37 (GPIO26)
GPIO27: X3.L13 (GPIO27), X3.P13 (GPIO27), X3.U13 (GPIO27)
ID_SC: R1.1, U1.6 (SCL), X3.L28 (ID_SC), X3.P28 (ID_SC), X3.U28 (ID_SC)
ID_SD: R2.1, U1.5 (SDA), X3.L27 (ID_SD), X3.P27 (ID_SD), X3.U27 (ID_SD)
unnamed: C7.1, C8.2, R14.1, U$1.5 (AIN1)
unnamed: C6.2, C8.1, R11.1, U$1.4 (AIN0)
unnamed: CFG.1, R3.1, U1.7 (WP)
unnamed: R5.2, SJ1.1
unnamed: R6.2, SJ1.3
unnamed: C17.1, C18.2, R10.1, U$3.4 (CH3)
unnamed: C16.2, C18.1, R7.1, U$3.3 (CH2)
unnamed: R23.2, SJ2.1
unnamed: R24.2, SJ2.3
unnamed: R25.2, SJ3.1
unnamed: R4.2, U$2.4 (BIAS), U$2.5 (REFIN+)
unnamed: R4.1, U$2.6 (REFIN-), U$2.7 (ISENSOR)
unnamed: C13.1, C14.2, R22.1, U$3.2 (CH1)
unnamed: C12.2, C14.1, R19.1, U$3.1 (CH0)
unnamed: C10.1, C11.2, R18.1, U$1.7 (AIN3)
unnamed: C9.2, C11.1, R15.1, U$1.6 (AIN2)
unnamed: R26.2, SJ3.3
unnamed: R27.2, SJ4.1
unnamed: R28.2, SJ4.3
RT1+: R5.1, R6.1, U$3.5 (CH4), X2.3
RT2+: R23.1, R24.1, U$3.6 (CH5), X2.4
RT3+: R25.1, R26.1, U$3.7 (CH6), X2.5
RT4+: R27.1, R28.1, U$3.8 (CH7), X2.6
RTD1+: C2.1, U$2.8 (FORCE+), U$2.10 (RTDIN+), X1.1
RTD1-: C2.2, U$2.11 (RTDIN-), U$2.12 (FORCE-), X1.2
SPI1_CE0: U$2.16 (!CS), X3.L12 (SPI1_CE0), X3.P12 (SPI1_CE0), X3.U12 (SPI1_CE0)
SPI1_CE1: U$1.2 (!CS), X3.L11 (SPI1_CE1), X3.P11 (SPI1_CE1), X3.U11 (SPI1_CE1)
SPI1_CE2: U$3.10 (!CS!/SHDN), X3.L36 (SPI1_CE2), X3.P36 (SPI1_CE2), X3.U36 (SPI1_CE2)
SPI1_MISO: U$1.9 (DOUT/!DRDY), U$2.17 (SDO), U$3.12 (DOUT), X3.L35 (SPI1_MISO), X3.P35 (SPI1_MISO), X3.U35 (SPI1_MISO)
SPI1_MOSI: U$1.10 (DIN), U$2.14 (SDI), U$3.11 (DIN), X3.L38 (SPI1_MOSI), X3.P38 (SPI1_MOSI), X3.U38 (SPI1_MOSI)
SPI1_SCLK: U$1.1 (SCLK), U$2.15 (SCLK), U$3.13 (CLK), X3.L40 (SPI1_SCLK), X3.P40 (SPI1_SCLK), X3.U40 (SPI1_SCLK)
TC1+: R11.2, R12.2, X1.3
TC1-: R13.1, R14.2, X1.4
TC2+: R17.1, R18.2, X1.5
TC2-: R15.2, R16.2, X1.6
TC3+: R19.2, R20.2, X1.7
TC3-: R21.1, R22.2, X1.8
TC4+: R7.2, R8.2, X2.1
TC4-: R9.1, R10.2, X2.2

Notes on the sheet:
Drawn by:
Checked by:
FLYFISH TECHNOLOGIES d.o.o.
Ivan Zilic
v0.1

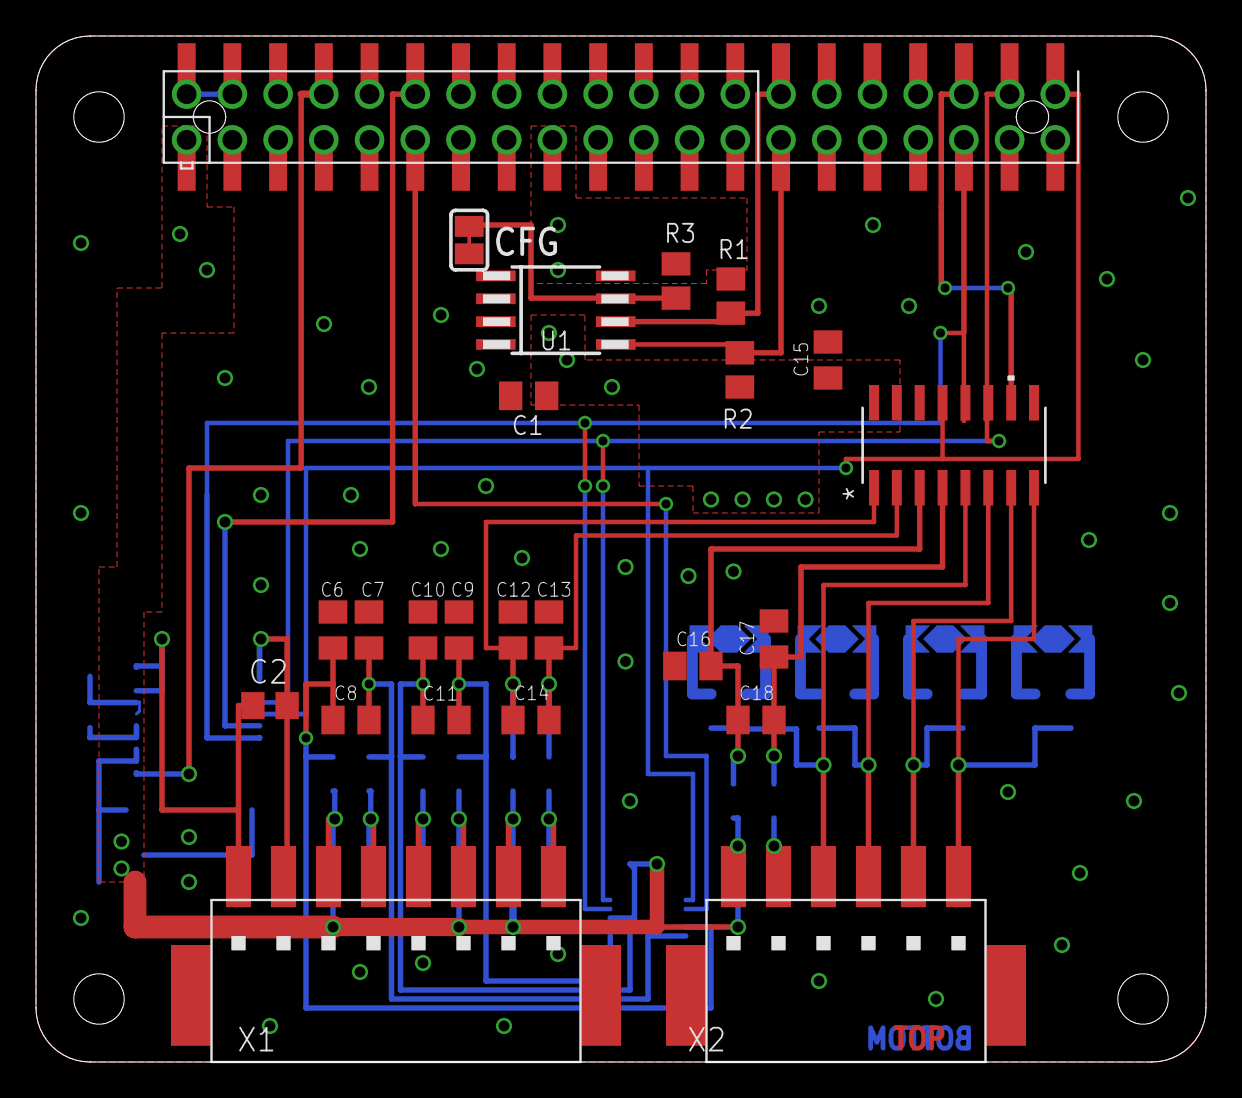
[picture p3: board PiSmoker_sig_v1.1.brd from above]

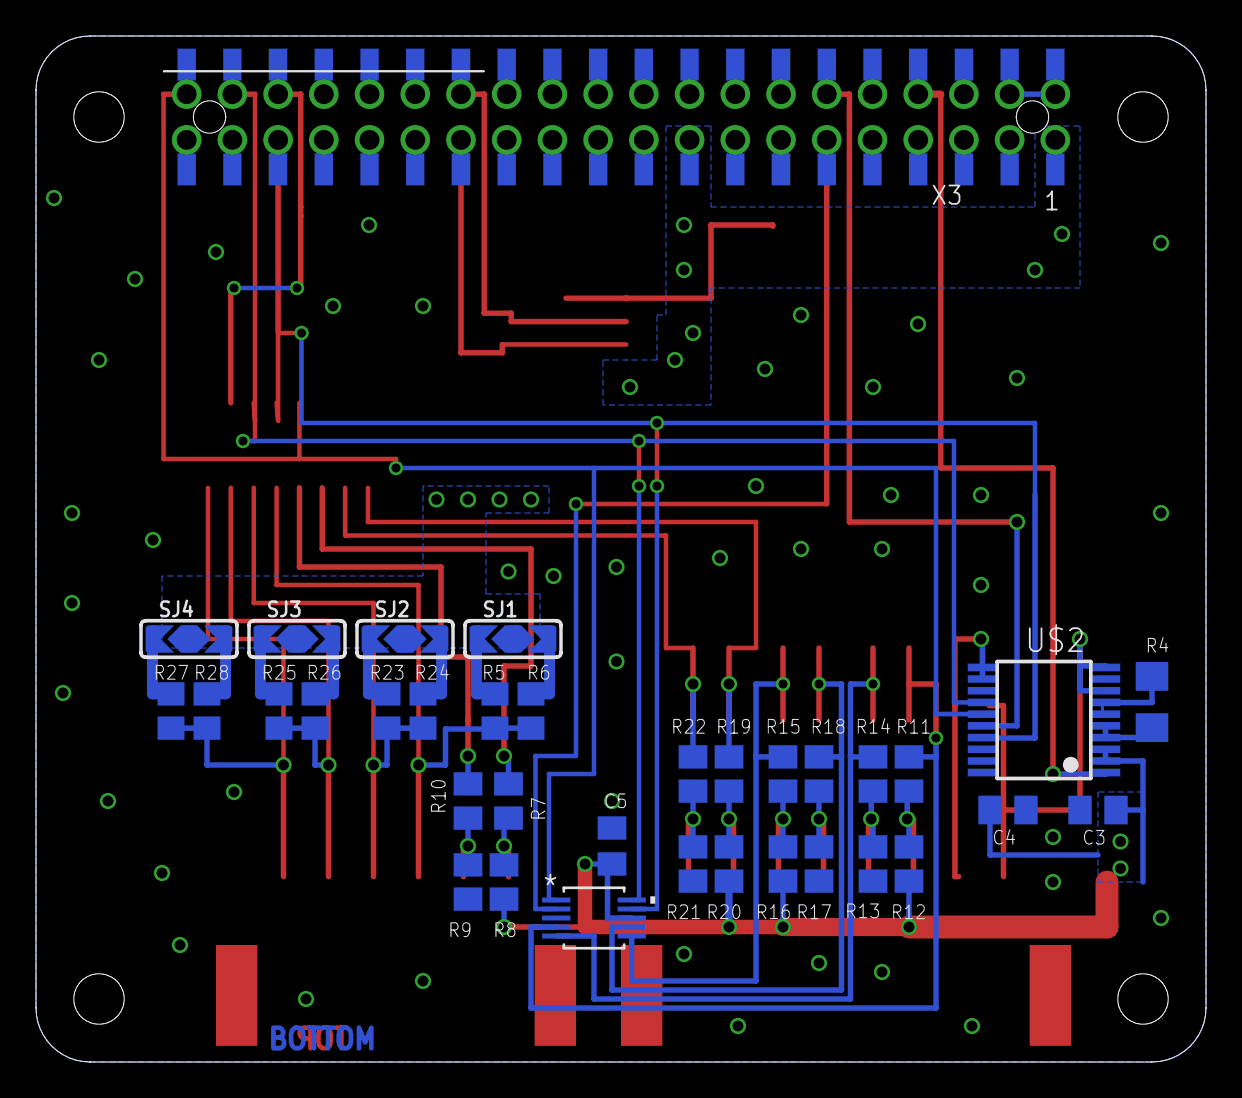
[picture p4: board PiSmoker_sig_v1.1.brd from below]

Board: 2 copper layers, 65.0 x 57.0 mm, 58 parts (34 on the bottom side), 64 nets.

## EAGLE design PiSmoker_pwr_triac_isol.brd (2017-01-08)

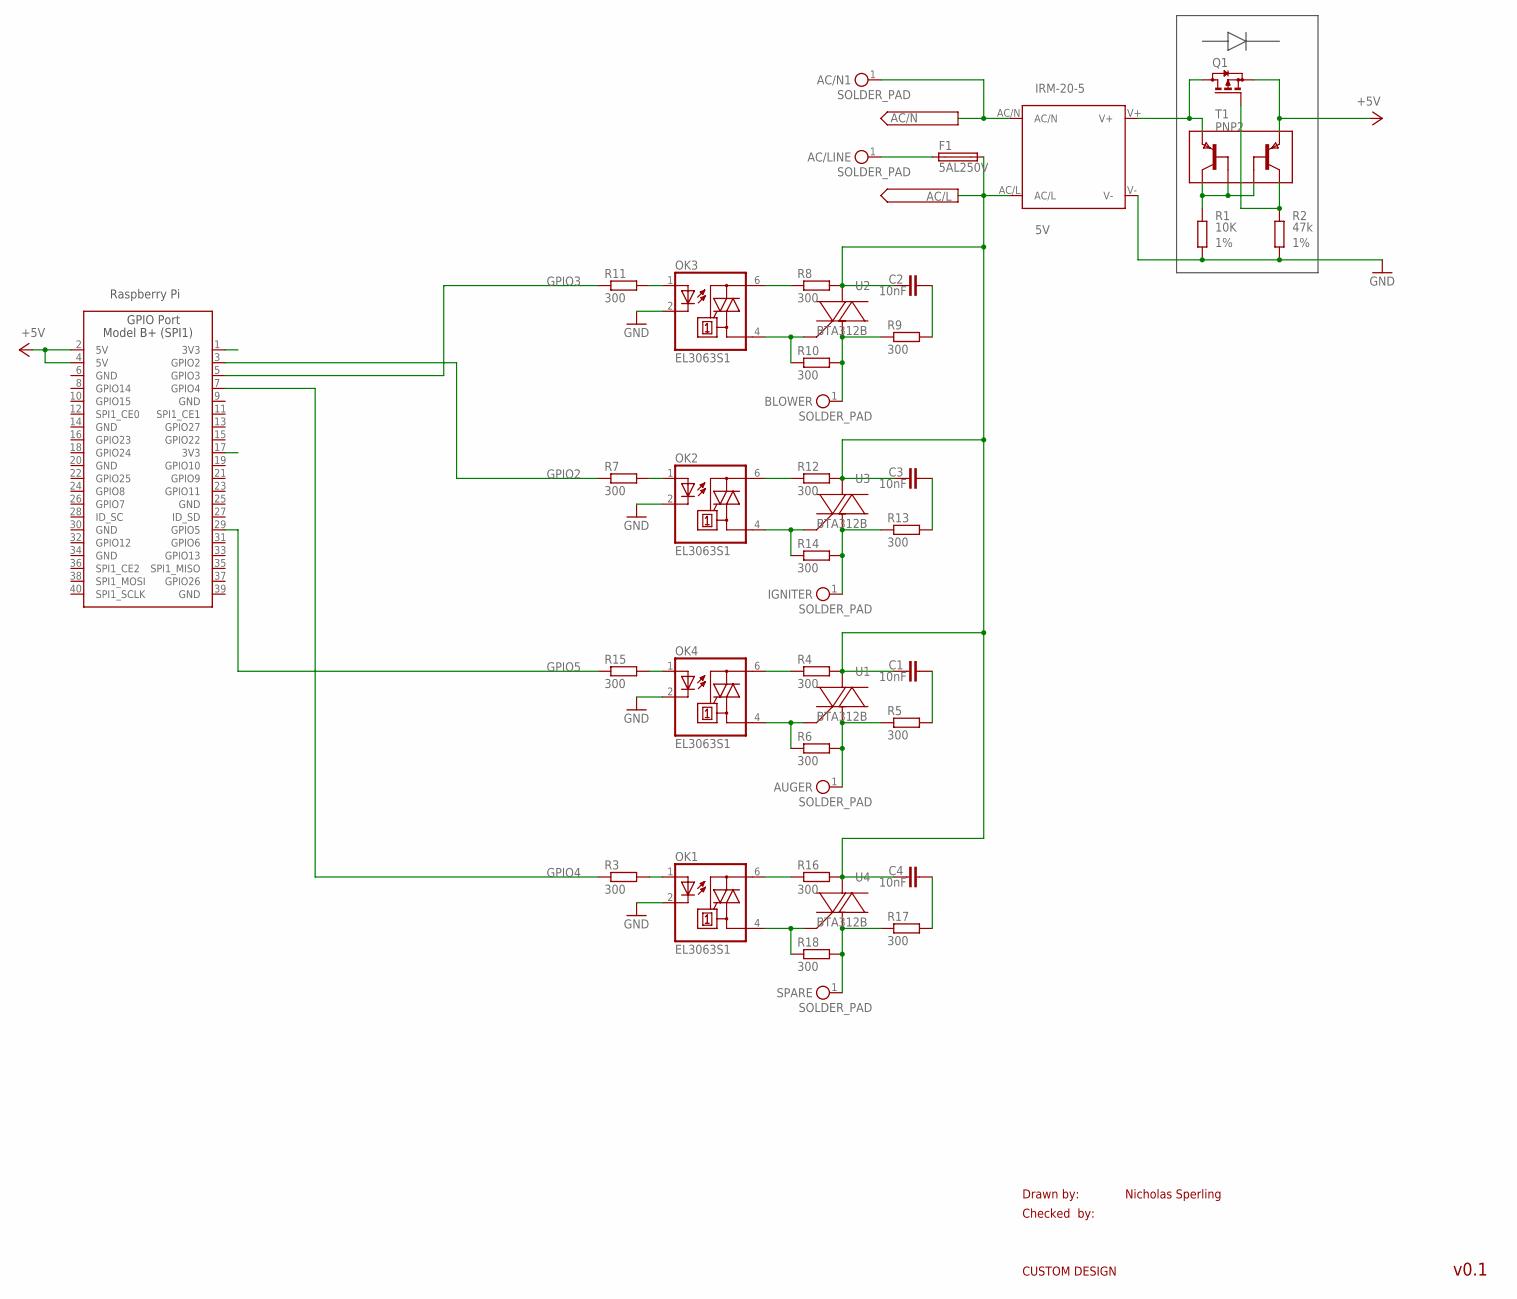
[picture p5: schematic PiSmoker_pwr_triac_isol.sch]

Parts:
AC/LINE: SOLDER_PAD; SOLDER_PAD_18AWG
AC/N1: SOLDER_PAD; SOLDER_PAD_18AWG
AUGER: SOLDER_PAD; SOLDER_PAD_18AWG
BLOWER: SOLDER_PAD; SOLDER_PAD_18AWG
C1, C2, C3, C4: 10nF; C1206
F1: 5AL250V; OGN_SMD
IGNITER: SOLDER_PAD; SOLDER_PAD_18AWG
IRM-20-5: 5V; IRM_15/20
OK1, OK2, OK3, OK4: EL3063S1; SMD6
Q1: BSS84; SOT23
R1: 10K; M0805; TOLERANCE 1%
R2: 47k; M0805; TOLERANCE 1%
R3, R4, R5, R6, R7, R8, R9, R10, R11, R12, R13, R14, R15, R16, R17, R18: 300; M0805; TOLERANCE 5%
SPARE: SOLDER_PAD; SOLDER_PAD_18AWG
T1: PNP2; SOT26
U1, U2, U3, U4: BTA312B; D2PAK-3
X1: RASPI_GPIO_3B_SPI1_M20-781_SMD_LOWER_NOHOLES; M20-781_SMD_LOWER_NOHOLES

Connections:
+5V: Q1.2 (S), T1.5 (E2), X1.2 (5V), X1.4 (5V)
AC/L: C1.1, C2.1, C3.1, C4.1, F1.2, IRM-20-5.AC/L, R4.2, R8.2, R12.2, R16.2, U1.MB (MT2), U2.MB (MT2), U3.MB (MT2), U4.MB (MT2)
AC/N: AC/N1.1, IRM-20-5.AC/N
AUGER_AC/L: AUGER.1, R5.1, R6.2, U1.1 (MT1)
BLOWER_AC/L: BLOWER.1, R9.1, R10.2, U2.1 (MT1)
GND: IRM-20-5.V-, OK1.2 (C), OK2.2 (C), OK3.2 (C), OK4.2 (C), R1.1, R2.1, X1.6 (GND), X1.9 (GND), X1.14 (GND), X1.20 (GND), X1.25 (GND), X1.30 (GND), X1.34 (GND), X1.39 (GND)
GPIO2: R7.1, X1.3 (GPIO2)
GPIO3: R11.1, X1.5 (GPIO3)
GPIO4: R3.1, X1.7 (GPIO4)
GPIO5: R15.1, X1.29 (GPIO5)
IGNITER_AC/L: IGNITER.1, R13.1, R14.2, U3.1 (MT1)
unnamed: C1.2, R5.2
unnamed: OK1.1 (A), R3.2
unnamed: C2.2, R9.2
unnamed: OK3.6 (A2), R8.1
unnamed: OK3.4 (A1), R10.1, U2.3 (G)
unnamed: OK2.1 (A), R7.2
unnamed: OK2.4 (A1), R14.1, U3.3 (G)
unnamed: OK2.6 (A2), R12.1
unnamed: C3.2, R13.2
unnamed: OK3.1 (A), R11.2
unnamed: OK4.6 (A2), R4.1
unnamed: IRM-20-5.V+, Q1.3 (D), T1.6 (E1)
unnamed: Q1.1 (G), R2.2, T1.4 (C2)
unnamed: R1.2, T1.1 (C1), T1.2 (B1), T1.3 (B2)
unnamed: OK4.4 (A1), R6.1, U1.3 (G)
unnamed: C4.2, R17.2
unnamed: OK4.1 (A), R15.2
unnamed: OK1.4 (A1), R18.1, U4.3 (G)
unnamed: OK1.6 (A2), R16.1
unnamed: AC/LINE.1, F1.1
SPARE_AC/L: R17.1, R18.2, SPARE.1, U4.1 (MT1)

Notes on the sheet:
Drawn by:
Checked by:
CUSTOM DESIGN
Nicholas Sperling
v0.1

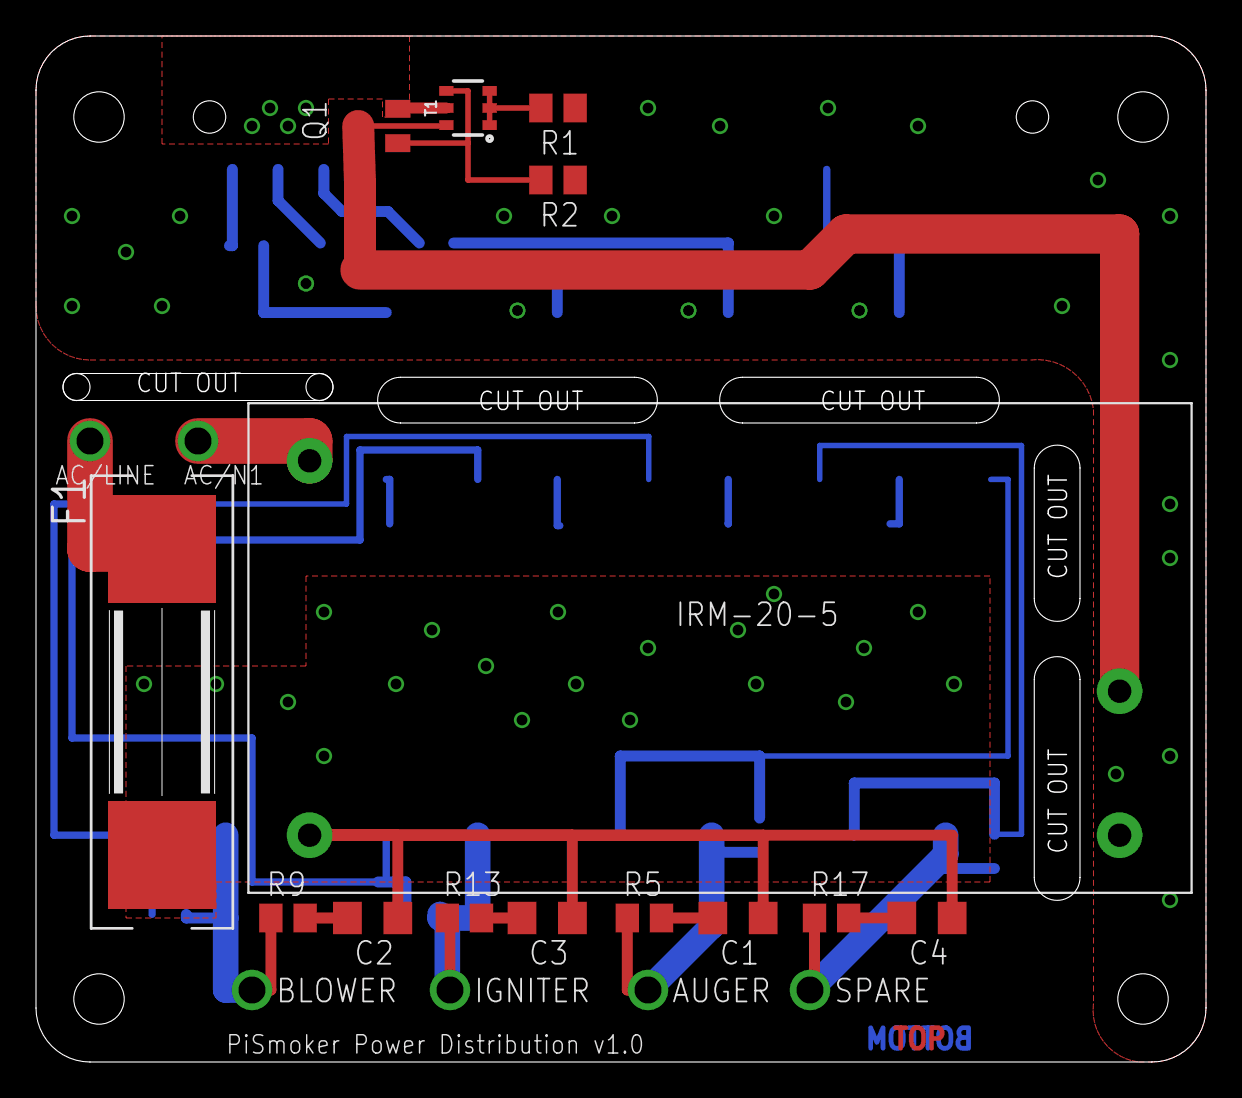
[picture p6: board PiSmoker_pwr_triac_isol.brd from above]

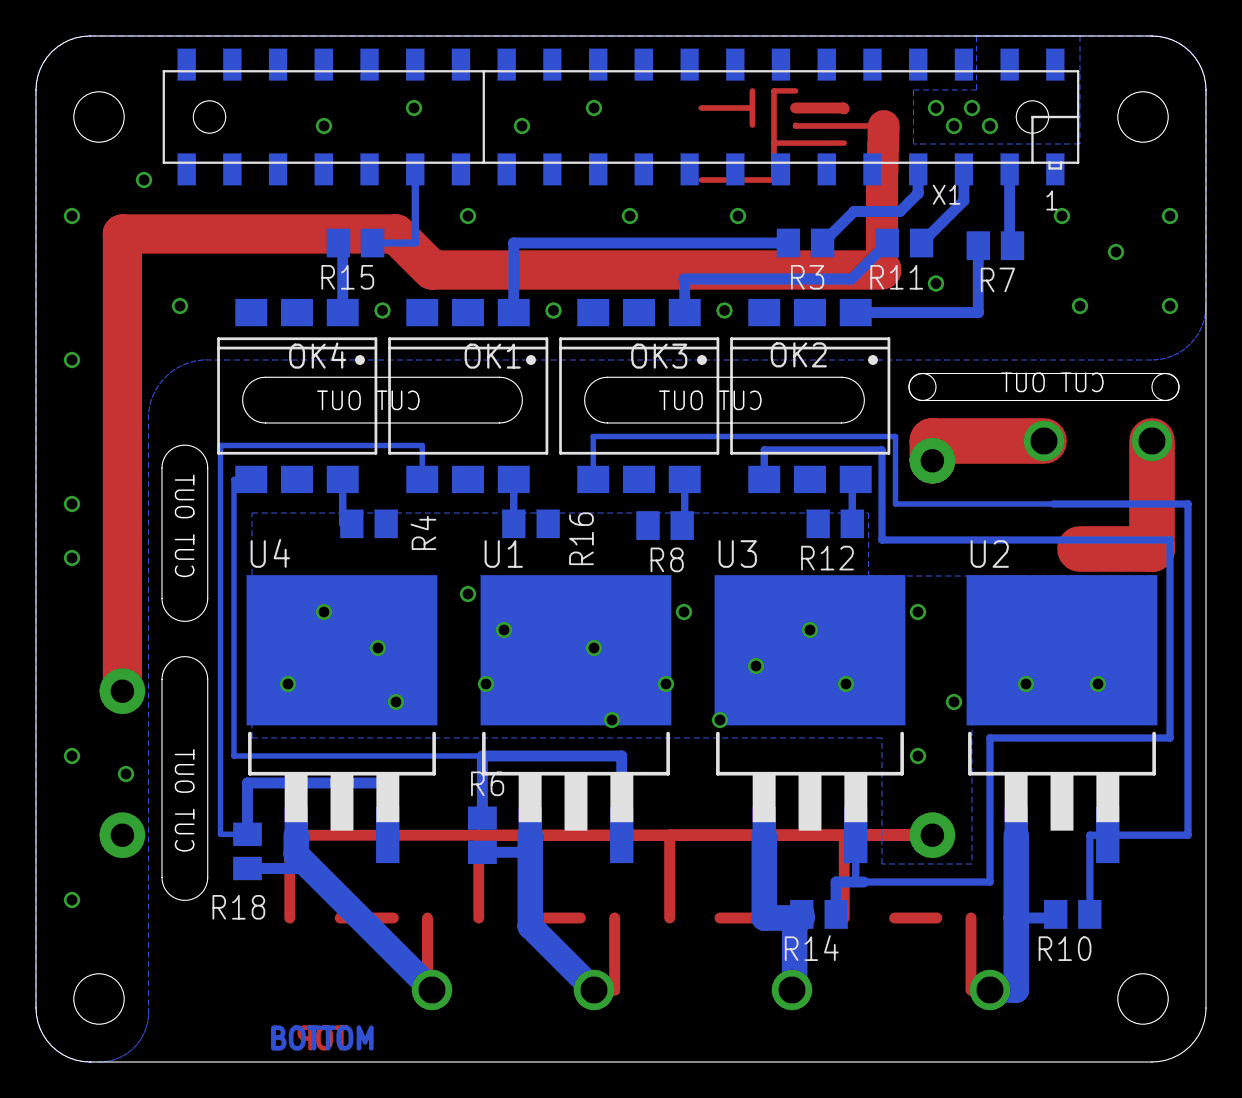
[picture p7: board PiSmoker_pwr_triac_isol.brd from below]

Board: 2 copper layers, 65.0 x 57.0 mm, 41 parts (20 on the bottom side), 32 nets.

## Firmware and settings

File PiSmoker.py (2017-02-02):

from Queue import Queue
from collections import deque
from logging import getLogger, config
from time import sleep, time

from ADS1118 import ADS1118
from FB_Handler import Firebase_Backend
from LCDDisplay import LCDDisplay
from MAX31865 import MAX31865
from PID import PID
from PiSmoker_Backend import PiSmoker_Backend
from TemperatureProbe import TemperatureProbe, RTD, THERMOCOUPLE
from Traeger import Traeger

SMOKER_AUTH_TOKEN_TXT = '/home/pi/PiSmoker/AuthToken.txt'

FB_URL = 'https://pismoker.firebaseio.com/'
PIDCycleTime = 20  # Frequency to update control loop
U_MIN = 0.15  # Maintenance level
U_MAX = 1.0  #
IGNITER_TEMP = 100  # Temperature to start igniter
STARTUP_TEMP = 115
SHUTDOWN_TIME = 10 * 60  # Time to run fan after shutdown
TEMP_INTERVAL = 3  # Frequency to record temperatures

_MEAT1_CHANNEL = '01'
_FIREBOX_CHANNEL = '23'

_BUS = 1
_MAX_CS = 0
_ADS_CS = 1
_MCS_CS = 2
# BCM GPIOs in use (TODO: Get from HAT)
# GPIO 2: Igniter
# GPIO 3: Blower
# GPIO 4: Spare
# GPIO 5: Auger
_RELAYS = {'auger': 5, 'fan': 3, 'igniter': 2}  # BCM

# Start logging
config.fileConfig('/home/pi/PiSmoker/logging.conf')
_logger = getLogger(__name__)


# noinspection SpellCheckingInspection
class Temperature_Record(deque):
    _average = None

    def __init__(self, iterable=(), maxlen=None):
        super(Temperature_Record, self).__init__(iterable, maxlen)
        self._update_average()

    def _update_average(self):
        if len(self) > 0:
            try:
                try:
                    self._average = {key: 0 for key in self[0]}
                    n = len(self) * 1.
                    for item in self:
                        for key in self._average:
                            self._average[key] += (item[key] / n)
                except LookupError or ValueError:
                    self._average = sum(self) / len(self)
            except StandardError:
                self._average = None
        else:
            self._average = None

    def average(self):
        return self._average

    def append(self, *args, **kwargs):
        to_return = super(Temperature_Record, self).append(*args, **kwargs)
        self._update_average()
        return to_return

    def appendleft(self, *args, **kwargs):
        to_return = super(Temperature_Record, self).appendleft(*args, **kwargs)
        self._update_average()
        return to_return

    def popleft(self, *args, **kwargs):
        to_return = super(Temperature_Record, self).popleft(*args, **kwargs)
        self._update_average()
        return to_return

    def pop(self, *args, **kwargs):
        to_return = super(Temperature_Record, self).pop(*args, **kwargs)
        self._update_average()
        return to_return

    def extendleft(self, *args, **kwargs):
        to_return = super(Temperature_Record, self).extendleft(*args, **kwargs)
        self._update_average()
        return to_return

    def extend(self, *args, **kwargs):
        to_return = super(Temperature_Record, self).extend(*args, **kwargs)
        self._update_average()
        return to_return

    def __delitem__(self, y):
        to_return = super(Temperature_Record, self).__delitem__(y)
        self._update_average()
        return to_return

    def clear(self, *args, **kwargs):
        to_return = super(Temperature_Record, self).clear(*args, **kwargs)
        self._update_average()
        return to_return

    def remove(self, value):
        to_return = super(Temperature_Record, self).remove(value)
        self._update_average()
        return to_return

    def __iadd__(self, y):
        to_return = super(Temperature_Record, self).__iadd__(y)
        self._update_average()
        return to_return

    def __setitem__(self, i, y):
        to_return = super(Temperature_Record, self).__setitem__(i, y)
        self._update_average()
        return to_return


class PiSmoker_Parameters(dict):
    """
    Modification of dict class to implement on_update callbacks
    """
    _setter_cb = None  # Signature:

    def __init__(self, setter_cb=None, *args, **kwargs):
        super(PiSmoker_Parameters, self).__init__(*args, **kwargs)

        if setter_cb:
            self._setter_cb = setter_cb

    def __setitem__(self, key, value):
        super(PiSmoker_Parameters, self).__setitem__(key, value)
        if self._setter_cb:
            self._setter_cb(key, value)


class PiSmoker(object):
    Parameters = None  # type: PiSmoker_Parameters
    db = None  # type: PiSmoker_Backend
    G = None  # type: Traeger
    Program = []
    qT = qR = qP = None  # type: Queue
    Control = None  # type: PID
    Temps = None  # type: Temperature_Record
    relays = None

    def __init__(self, db, qT=None, qR=None, qP=None, relays=None):
        """

        @param db: Database backend, expects methods from PiSmoker_Backend
        @type db: PiSmoker_Backend.PiSmoker_Backend
        @param relays: [Optional]Dictionary of relay names and GPIO pins
        @type relays: dict
        """
        self.Parameters = PiSmoker_Parameters(self.ParameterUpdateCallback,
                {'mode':  'Off', 'target': 225, 'PB': 60.0, 'Ti': 180.0, 'Td': 45.0, 'CycleTime': PIDCycleTime,
                 'u': U_MIN, 'PMode': 2.0, 'program': False, 'ProgramToggle': time()})  # 60,180,45 held +- 5F
        # Initialize Traeger Object
        if relays:
            self.relays = relays
        else:
            self.relays = _RELAYS
        self.G = Traeger(self.relays)
        self.db = db

        self.qT = qT or Queue()
        self.qR = qR or Queue()
        self.qP = qP or Queue()

        # PID controller based on proportional band in standard PID form
        # https://en.wikipedia.org/wiki/PID_controller#Ideal_versus_standard_PID_form
        # u = Kp (e(t)+ 1/Ti INT + Td de/dt)
        # PB = Proportional Band
        # Ti = Goal of eliminating in Ti seconds (Make large to disable integration)
        # Td = Predicts error value at Td in seconds

        # Start controller
        self.Control = PID(self.Parameters['PB'], self.Parameters['Ti'], self.Parameters['Td'])
        self.Control.setTarget(self.Parameters['target'])

        self.Temps = Temperature_Record(maxlen=int(self.Parameters['CycleTime'] / TEMP_INTERVAL))
        # Set mode
        self.ModeUpdated()

    def UpdateTemps(self, probe_list):
        """

        @param probe_list: List of probes which provide the read() function to get the temperature.
        @type probe_list: [TemperatureProbe.TemperatureProbe,...]
        @return:
        @rtype:
        """
        now = time()
        if not self.Temps or now - self.Temps[-1]['time'] > TEMP_INTERVAL:
            Ts = {'time': now}
            Ts.update({probe: probe_list[probe].read() for probe in probe_list})
            self.Temps.append(Ts)
            _logger.info("Temps: %r" % self.Temps[-1])
            self.db.PostTemps(self.Parameters['target'], Ts)

            # Push temperatures to LCD
            #self.qT.put(Ts)

    def readLCD(self):
        NewParameters = {}
        while not self.qR.empty():
            NewParameters.update(self.qR.get())
        return NewParameters

    def ParameterUpdateCallback(self, parameter, value):
        _logger.info('New Parameters: %s -- %r (%r)', parameter, float(value), self.Parameters[parameter])
        if parameter == 'target':
            self.Control.setTarget(float(value))
        elif parameter in ['PB', 'Ti', 'Td']:
            self.Control.setGains(self.Parameters['PB'], self.Parameters['Ti'], self.Parameters['Td'])
        elif parameter == 'PMode':
            self.ModeUpdated()
        elif parameter == 'mode':
            self.ModeUpdated()
        elif parameter == 'program':
            self.ReadProgram()
            self.ProcessProgram()
            # TODO: Figure out reason for break after program
            # break  # Stop processing new parameters - not sure why?
        # Write parameters back after all changes have been handled.
        self.db.WriteParameters(self.Parameters)

    def UpdateParameters(self):
        # Loop through each key, see what changed
        NewParameters = self.db.ReadParameters() or {}
        NewParameters.update(self.readLCD())
        for k in NewParameters.keys():
            _logger.info('New self.Parameters: %s -- %r (%r)', k, float(NewParameters[k]), self.Parameters[k])
            if k in ['target', 'PB', 'Ti', 'Td', 'PMode']:
                if float(self.Parameters[k]) != float(NewParameters[k]):
                    self.Parameters[k] = float(NewParameters[k])
            elif k == 'mode':
                if self.Parameters[k] != NewParameters[k]:
                    self.Parameters[k] = NewParameters[k]
            elif k == 'program':
                if self.Parameters[k] != NewParameters[k]:
                    self.Parameters[k] = NewParameters[k]
                    self.Parameters['LastReadProgram'] = time() - 10000
                    # TODO: Figure out reason for break after program
                    # break  # Stop processing new parameters - not sure why?
            elif k == 'CycleTime':
                if self.Parameters[k] != NewParameters[k]:
                    self.Parameters[k] = NewParameters[k]
                    self.Temps = Temperature_Record(self.Temps or (), maxlen=int(self.Parameters[k] / TEMP_INTERVAL))

    def GetAverageSince(self, startTime, probe='grill'):
        # TODO: Rolling average
        n = 0
        total = 0
        for Ts in self.Temps:
            if Ts['time'] < startTime:
                continue
            total += Ts[probe]
            n += 1
        return total / n

    # Modes
    def ModeUpdated(self):
        if self.Parameters['mode'] == 'Off':
            _logger.info('Setting mode to Off')
            self.G.Initialize()

        elif self.Parameters['mode'] == 'Shutdown':
            self.G.Initialize()
            self.G.SetState('fan', True)

        elif self.Parameters['mode'] == 'Start':
            self.G.SetState('fan', True)
            self.G.SetState('auger', True)
            self.G.SetState('igniter', True)
            self.Parameters['CycleTime'] = 15 + 45
            self.Parameters['u'] = 15.0 / (15.0 + 45.0)  # P0

        elif self.Parameters['mode'] == 'Smoke':
            self.G.SetState('fan', True)
            self.G.SetState('auger', True)
            self.CheckIgniter()
            On = 15
            Off = 45 + self.Parameters['PMode'] * 10  # http://tipsforbbq.com/Definition/Traeger-P-Setting
            self.Parameters['CycleTime'] = On + Off
            self.Parameters['u'] = On / (On + Off)

        elif self.Parameters['mode'] == 'Ignite':  # Similar to smoke, with igniter on
            self.G.SetState('fan', True)
            self.G.SetState('auger', True)
            self.G.SetState('igniter', True)
            On = 15
            Off = 45 + self.Parameters['PMode'] * 10  # http://tipsforbbq.com/Definition/Traeger-P-Setting
            self.Parameters['CycleTime'] = On + Off
            self.Parameters['u'] = On / (On + Off)

        elif self.Parameters['mode'] == 'Hold':
            self.G.SetState('fan', True)
            self.G.SetState('auger', True)
            self.CheckIgniter()
            self.Parameters['CycleTime'] = PIDCycleTime
            self.Parameters['u'] = U_MIN  # Set to maintenance level

        self.WriteParameters()

    def DoMode(self):
        now = time()
        if self.Parameters['mode'] == 'Off':
            pass

        elif self.Parameters['mode'] == 'Shutdown':
            if (now - self.G.ToggleTime['fan']) > SHUTDOWN_TIME:
                self.Parameters['mode'] = 'Off'
                self.ModeUpdated()

        elif self.Parameters['mode'] == 'Start':
            self.DoAugerControl()
            self.G.SetState('igniter', True)
            if self.Temps[-1]['grill'] > STARTUP_TEMP:
                self.Parameters['mode'] = 'Hold'
                self.ModeUpdated()

        elif self.Parameters['mode'] == 'Smoke':
            self.DoAugerControl()

        elif self.Parameters['mode'] == 'Ignite':
            self.DoAugerControl()
            self.G.SetState('igniter', True)

        elif self.Parameters['mode'] == 'Hold':
            self.DoControl()
            self.DoAugerControl()

    def WriteParameters(self):
        """Write parameters to file"""

        for r in self.relays:
            self.Parameters[r] = self.G.GetState(r)

        self.Parameters['LastWritten'] = time()
        self.qP.put(self.Parameters)

        self.db.WriteParameters(self.Parameters)

    def DoAugerControl(self):
        # Auger currently on AND TimeSinceToggle > Auger On Time
        if self.G.GetState('auger') and (time() - self.G.ToggleTime['auger']) > self.Parameters['CycleTime'] * \
                self.Parameters['u']:
            if self.Parameters['u'] < 1.0:
                self.G.SetState('auger', False)
                self.WriteParameters()
            self.CheckIgniter()

        # Auger currently off AND TimeSinceToggle > Auger Off Time
        if (not self.G.GetState('auger')) and (time() - self.G.ToggleTime['auger']) > self.Parameters['CycleTime'] * \
                (1 - self.Parameters['u']):
            self.G.SetState('auger', True)
            self.CheckIgniter()
            self.WriteParameters()

    def CheckIgniter(self):
        # Check if igniter needed
        # TODO: Update igniter check code
        if self.Temps[-1]['grill'] < IGNITER_TEMP:
            self.G.SetState('igniter', True)
        else:
            self.G.SetState('igniter', False)

        # Check if igniter has been running for too long
        if (time() - self.G.ToggleTime['igniter']) > 1200 and self.G.GetState('igniter'):
            _logger.info('Disabling igniter due to timeout')
            self.G.SetState('igniter', False)
            self.Parameters['mode'] = 'Shutdown'
            self.ModeUpdated()

    def DoControl(self):
        if (time() - self.Control.LastUpdate) > self.Parameters['CycleTime']:
            self.Parameters['u'] = min(max(self.Control.update(self.Temps.average()['grill']), U_MIN), U_MAX)
            _logger.info('u %f', self.Parameters['u'])

            # Post control state
            D = {'time':  time() * 1000, 'u': self.Parameters['u'], 'P': self.Control.P, 'I': self.Control.I,
                 'D':     self.Control.D,
                 'PID':   self.Control.u, 'Error': self.Control.error, 'Derv': self.Control.Derv,
                 'Inter': self.Control.Inter}

            self.db.WriteControl(D)

            self.WriteParameters()

        return self.Parameters

    def ReadProgram(self):
        # Check if program is new
        NewProgram = self.db.ReadProgram(self.Parameters['program'])
        if NewProgram and self.Program != NewProgram:
            _logger.info('Detected new program')
        self.SetProgram(NewProgram)

    def EvaluateTriggers(self):
        now = time()
        if self.Parameters['program'] and len(self.Program) > 0:
            P = self.Program[0]

            if P['trigger'] == 'Time':
                if now - self.Parameters['ProgramToggle'] > float(P['triggerValue']):
                    self.NextProgram()

            elif P['trigger'] == 'MeatTemp':
                if self.Temps[-1]['meat'] > float(P['triggerValue']):
                    self.NextProgram()

    def NextProgram(self):
        _logger.info('Advancing to next program')
        self.Program.pop(0)  # Remove current program

        self.db.WriteProgram(self.Program)
        if len(self.Program) > 0:
            self.ProcessProgram()
        else:
            _logger.info('Last program reached, disabling program')
            self.Parameters['program'] = False
            self.WriteParameters()

    def ProcessProgram(self):
        if self.Program:
            if len(self.Program) > 0:
                self.Parameters['ProgramToggle'] = time()

                P = self.Program[0]
                self.Parameters['mode'] = P['mode']
                self.ModeUpdated()

                self.Parameters['target'] = float(P['target'])
                self.Control.setTarget(self.Parameters['target'])
                self.WriteParameters()

            else:
                _logger.info('Last program reached, disabling program')
                self.Parameters['program'] = False
                self.WriteParameters()

    def SetProgram(self, Program):
        self.Program = Program
        self.ProcessProgram()


def main(*args, **kwargs):
    # Initialize Probes
    grill_ADC = MAX31865(bus=_BUS, cs=_MAX_CS, R_ref=4000.)
    ADS_ADC = ADS1118(bus=_BUS, cs=_ADS_CS)

    grill_probe = TemperatureProbe(RTD, read_fn=grill_ADC.read, temp_in_F=True)
    meat1_probe = TemperatureProbe(THERMOCOUPLE, read_fn=ADS_ADC.read, read_fn_kwargs={'channel': _MEAT1_CHANNEL},
                                   read_cj_fn=ADS_ADC.read_its, temp_in_F=True)
    firebox_probe = TemperatureProbe(THERMOCOUPLE, read_fn=ADS_ADC.read, read_fn_kwargs={'channel': _FIREBOX_CHANNEL},
                                     read_cj_fn=ADS_ADC.read_its, temp_in_F=True)
    Probes = {'grill':   grill_probe,
              'meat':    meat1_probe,
              'firebox': firebox_probe}

    # Start firebase
    auth_file = SMOKER_AUTH_TOKEN_TXT
    if 'auth' in kwargs:
        auth_file = kwargs['auth']
    elif len(args) > 0:
        auth_file = args[0]
    f = open(auth_file, 'r')
    Secret = f.read()
    f.close()
    firebase_db = Firebase_Backend(FB_URL, Secret)

    # Initialize LCD
    qP = Queue()  # Queue for Parameters
    qT = Queue()  # Queue for Temps
    qR = Queue()  # Return for Parameters
    qT.put({'time':0, 'grill': 0, 'meat1': 0})
    #lcd = LCDDisplay(qP, qT, qR)
    #lcd.setDaemon(True)
    #lcd.start()

    ##############
    # Setup       #
    ##############

    # Default parameters
    Smoker = PiSmoker(firebase_db, qT=qT, qP=qP, qR=qR, relays=_RELAYS)

    # Setup variables
    # Parameters['LastReadProgram'] = time.time()
    # Parameters['LastReadWeb'] = time.time()

    ###############
    # Main Loop    #
    ###############
    sleep(5)  # Wait for clock to sync
    _return_value = 1
    #try:
    while 1:
        # Record temperatures
        Smoker.UpdateTemps(Probes)

        # Check for new parameters
        Smoker.UpdateParameters()

        # Check for new program
        Smoker.ProcessProgram()

        # Evaluate triggers
        Smoker.EvaluateTriggers()

        # Do mode
        Smoker.DoMode()

        sleep(0.05)
    #except KeyboardInterrupt:
    #    _return_value = 0
    #    pass
    #finally:
    #    for relay in Smoker.relays:
    #        # Shutdown all relays if possible.
    #        Smoker.G.SetState(relay_id=relay, state=False)
    #    return _return_value


if __name__ == '__main__':
    import sys

    return_value = main()
    sys.exit(return_value)

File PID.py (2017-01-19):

import logging.config
import time

# Start logging
logging.config.fileConfig('/home/pi/PiSmoker/logging.conf')
logger = logging.getLogger(__name__)


# PID controller based on proportional band in standard PID form
# https://en.wikipedia.org/wiki/PID_controller#Ideal_versus_standard_PID_form
# u = Kp (e(t)+ 1/Ti INT + Td de/dt)
# PB = Proportional Band
# Ti = Goal of eliminating in Ti seconds
# Td = Predicts error value at Td in seconds

class PID:
    P = I = D = u = Derv = Inter = Inter_max = None
    Kp = Ki = Kd = None
    LastUpdate = error = setPoint = None

    def __init__(self, PB, Ti, Td):
        self.CalculateGains(PB, Ti, Td)

        self.P = 0.0
        self.I = 0.0
        self.D = 0.0
        self.u = 0

        self.Derv = 0.0
        self.Inter = 0.0
        self.Inter_max = abs(0.5 / self.Ki)

        self.Last = 150

        self.setTarget(0.0)

    def CalculateGains(self, PB, Ti, Td):
        self.Kp = -1 / PB
        self.Ki = self.Kp / Ti
        self.Kd = self.Kp * Td
        logger.info('PB: %f Ti: %f Td: %f --> Kp: %f Ki: %f Kd: %f', PB, Ti, Td, self.Kp, self.Ki, self.Kd)

    def update(self, Current):
        now = time.time()
        # P
        error = Current - self.setPoint
        self.P = self.Kp * error + 0.5  # P = 1 for PB/2 under setPoint, P = 0 for PB/2 over setPoint

        # I
        dT = now - self.LastUpdate
        # if self.P > 0 and self.P < 1: #Ensure we are in the PB, otherwise do not calculate I to avoid windup
        self.Inter += error * dT
        self.Inter = max(self.Inter, -self.Inter_max)
        self.Inter = min(self.Inter, self.Inter_max)

        self.I = self.Ki * self.Inter

        # D
        self.Derv = (Current - self.Last) / dT
        self.D = self.Kd * self.Derv

        # PID
        self.u = self.P + self.I + self.D

        # Update for next cycle
        self.error = error
        self.Last = Current
        self.LastUpdate = now

        logger.info('Target: %d Current: %d Gains: (%f,%f,%f) Errors(%f,%f,%f) Adjustments: (%f,%f,%f) PID: %f',
                    self.setPoint, Current, self.Kp, self.Ki, self.Kd, error, self.Inter, self.Derv, self.P, self.I,
                    self.D, self.u)

        return self.u

    def setTarget(self, setPoint):
        self.setPoint = setPoint
        self.error = 0.0
        self.Inter = 0.0
        self.Derv = 0.0
        self.LastUpdate = time.time()
        logger.info('New Target: %f', setPoint)

    def setGains(self, PB, Ti, Kd):
        self.CalculateGains(PB, Ti, Kd)
        self.Inter_max = abs(0.5 / self.Ki)
        logger.info('New Gains (%f,%f,%f)', self.Kp, self.Ki, self.Kd)

    def getK(self):
        return self.Kp, self.Ki, self.Kd

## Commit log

2015-12-02 Fixed ReadParameters return on failure
    [PiSmoker.py]
2016-01-11 Moved a WriteParameters to avoid constant updates.
    [PiSmoker.py]
2016-01-30 Added 3 wire configuration
2016-03-28 Fixed config for MAX31865 for 3 wire configuration
    [MAX31865.py]
2017-01-08 Uploaded schematic and board files for PiSmoker
    Signal board and power board for traic based control. Includes board power with isolation and 4 triacs. Signaling board has space for 1 RTD via MAX31865, 2 thermocouples (and internal temperature sen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
    [PiSmoker_pwr_triac_isol.brd, PiSmoker_pwr_triac_isol.sch, PiSmoker_sig_v1.1.brd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]
2017-01-08 Add BOM and ordering details for mouser.
    Bill of materials, placement details, and mouser part numbers with messup margins.
    [Ordering.ods]
2017-01-13 Update TODO, begin trager class rework, including option for GPIO inversion.
    [Traeger.py]
2017-01-17 Work on new generic temperature probe class, incl. thermocouple data.
2017-01-18 Continue implementation of ADC chips and temperature probe class.
2017-01-20 Refactored into class, begin board specific implementation.
2017-01-26 Bugfix in TemperatureProbe and ASD1118 (^ is XOR not **) Added per channel gain for ADS1118
    [ADS1118.py, TemperatureProbe.py]
2017-01-26 Continue refactor of main code. Changing handling of temperature log (only hold the temps needed in memory and implement a rolling average class)
2017-02-02 Debugging interfaces. Bug in SpiDev requires bitbanged SPI for ADS1118. Lots of bug fixes.
    [ADS1118.py, FB_Handler.py, LCDDisplay.py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]

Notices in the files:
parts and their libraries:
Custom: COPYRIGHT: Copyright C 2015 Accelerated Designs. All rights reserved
